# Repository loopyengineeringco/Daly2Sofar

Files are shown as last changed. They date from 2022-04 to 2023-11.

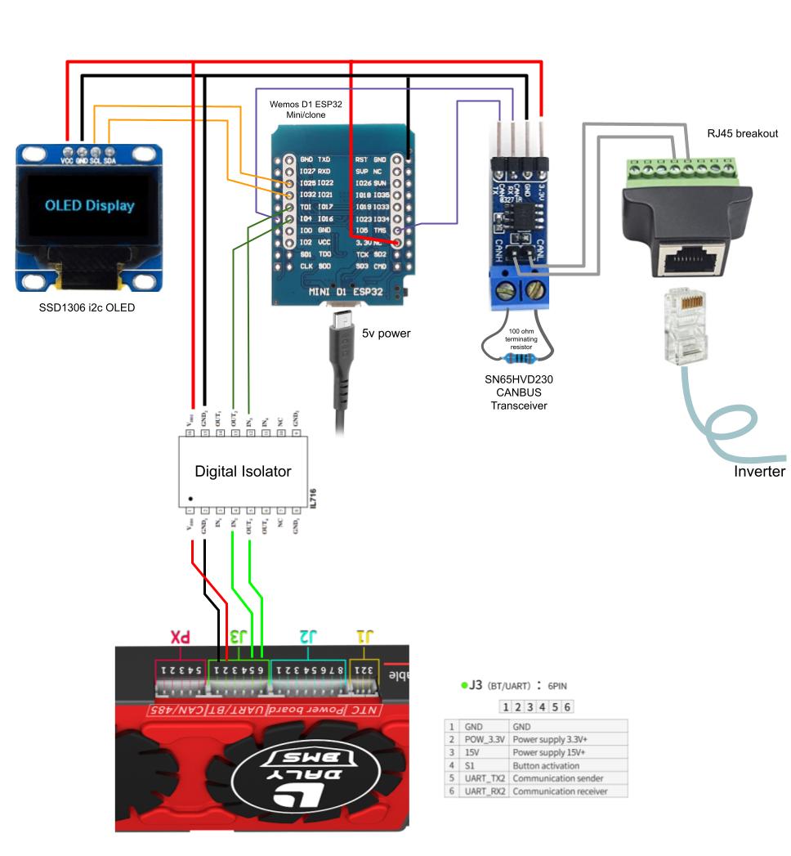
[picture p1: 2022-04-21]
Daly2Sofar schematic.jpg

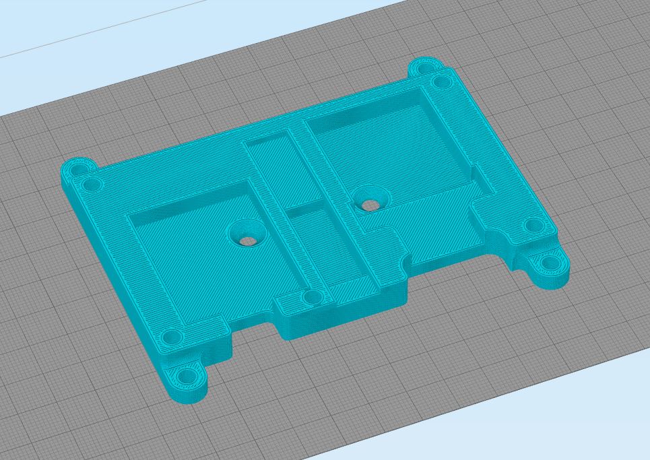
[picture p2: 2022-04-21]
3D Printables/Base_slicer.JPG

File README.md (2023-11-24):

# !!!
Due to updates to the Daly library dependency, compilation might throw an error.
Please look at the Issues page for the temporary solution while I do further testing, or use the older version of the Daly lib which is in the Arduino dependencies folder.
!!!

# Daly2Sofar v0.93 - beta
ESP32 bridge allowing Daly Smart BMS to be used with a Sofar inverter/charger (and others that use SMA CANBUS protocol).


It connects to Daly via UART and transmits to the inverter on CANBUS (SMA protocol).
At the same time, it will transmit the BMS data to an MQTT broker if it can connect to your WiFi.
If it can't connect to WiFi or your MQTT broker, it will still work as a BMS-to-Inverter bridge.
The icons on the OLED represent the WiFi & MQTT status. They will be crossed out if there is no connection.

Data comms is one way only - data is requested from Daly and sent to the Inverter & over MQTT.
May be compatible with other inverters that use the SMA protocol.

My testing showed that Daly UART port works on 3.3v. PLEASE measure yours before connecting the ESP. Some users report 5V.



Daly2Sofar_3

# PSA:
USE THIS AT YOUR OWN RISK!
Batteries are dangerous. Don't come to me if you burn your house down.
This release is a working prototype. It might freeze, there might be glitches. Your battery might overcharge/undercharge. Make sure your BMS is set up properly with your own limits.
USE THIS AT YOUR OWN RISK!

# Schematic


# Isolation
Some battery setups earth the battery negative, others don't.
For the ones that aren't earthed, you may get a ID05 Fault on the inverter when you connect canbus.
You might get a shock if you touch the comms/3v3/ground pins coming from the BMS, even though they're supposed to be only 3.3v.

Ask me how I know!

This is because the Daly UART ground is battery ground, and it makes its way to the inverter.
It might be higher or lower voltage potential, in respect to earth.

The Daly needs to be isolated in this case, using a digital isolation IC.
Opto-coupler's don't work as the signal becomes inverted. ESP32 serial can be inverted by software but Daly can't.
IL716-3E based isolator IC works, as well as the cheap off-the shelf ADUM1201 based modules.

# ESP32 pin remapping
Make sure the I2C pins are mapped correctly for the Oled to work. For me, pins 21 and 22 work great
C:\Users\XXXXX\Documents\Arduino\libraries\Adafruit_SSD1306-1.1.2\Adafruit_SSD1306.cpp
```
#define I2C_SDA 21
#define I2C_SCL 22
```

And also Serial2 needs to be correctly mapped in this file (This is Windows. Sorry I don't know where it is on a Mac)
C:\Users\XXXXX\AppData\Local\Arduino15\packages\esp32\hardware\esp32\1.0.6\cores\esp32\HardwareSerial.cpp
Look for this near the top:
```
#ifndef RX2
#define RX2 16
#endif

#ifndef TX2
#define TX2 17
#endif
```

# MQTT info:
Add your WiFi and MQTT details to the top of the sketch, as well as your battery capacity and preferred charging voltage (Capacity is broken at the moment, but the Inverter seems happy nonetheless):



Subscribe your MQTT client to:
```Daly2Sofar/state```

topics published are:
```
soc
voltage
current
power
temp
lowestcell
highestcell
cellimbalance
```

# Node-RED
For extracting the data into Home Asisstant sensors, use Node-Red. You can import the ```Daly2Sofar Node-Red to Home Assistant flow.json```flow to extract the data into sensor entities, it will look like this:
![image](https://user-images.githubusercontent.com/43951291/166910404-52b77566-ff52-444a-bd41-08b7f5ddcaa1.png)

(you may need to install Moving Average filter if you want smoothing of data)

When the battery is discharging, Node-RED will calculate the remaining battery time based on the current discharge rate.
When it's charging, it will calculate the time left to full charge.
Because charging/discharging and SOC isn't linear, this value is only a rough estimation, but useful nonetheless.

This has some hard-coded variables - it's based on a 10kWh battery and 80% DOD, and also what percentage to consider 'full' 95% in my case.
Make sure you customise them if you want to use this Flow :-)
![image](https://user-images.githubusercontent.com/43951291/166910615-47297ec8-0477-4fcf-b30d-cc008e25f745.png)

Home Assistant dashboard example
![image](https://user-images.githubusercontent.com/43951291/166928175-bbf1b5a7-a5f7-41d0-8a70-b6e47e459800.png)

# To do:
- Do proper CANBUS status check. Currently, CAN indicator will go live after the data send, whether it's succesfull or not.
- Add battery cycles: the owner of the Daly library is adding the functionality, and it will be reflected here when it's done.
- Add charge/discharge control via MQTT (as soon as it's available in the Daly lib)
- Tidy up code/refactor where poss.
- Longer term stability testing.

# Arduino dependencies

https://github.com/maland16/daly-bms-uart

https://github.com/miwagner/ESP32-Arduino-CAN

https://github.com/me-no-dev/AsyncTCP

https://github.com/marvinroger/async-mqtt-client

https://github.com/adafruit/Adafruit_SSD1306

# Notes/links

CANH & CANL can be live swapped. If display is saying all is good but inverter isn't happy, try swapping the wires.

Developed on Arduino IDE 1.8.5. Version 1.8.14 failed to compile. Downgrade if you have issues

Using arduino ESP32 Core version 1.0.6

Developed & tested with a Sofar HYD6000-ES. Should work fine with all the others, but if you test it on your inverters let me know how it goes!

Using SMA_CAN_protocol.pdf for the CAN IDs and data format info (google will find you the PDF)

Using https://cryptii.com/pipes/integer-encoder for working out hex values

VIEW TEXT > DECODE INTEGER (LITTLE ENDIAN) U16 > VIEW BYTES HEX GROUPED BY BYTES

https://www.scadacore.com/tools/programming-calculators/online-hex-converter/ for checking hex values

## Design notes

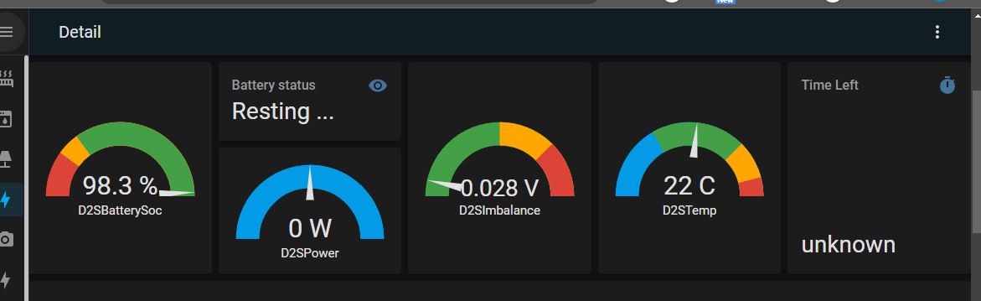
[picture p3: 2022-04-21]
Home Assistant sensors example.jpg

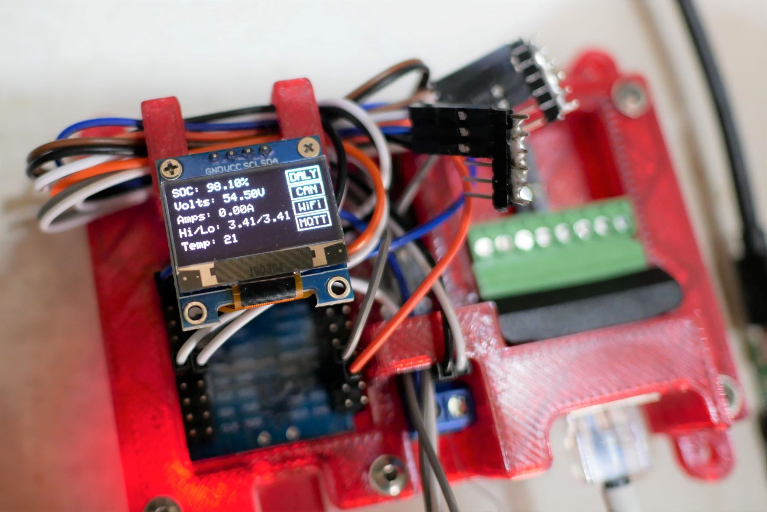
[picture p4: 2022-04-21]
Daly2Sofar_2.jpg

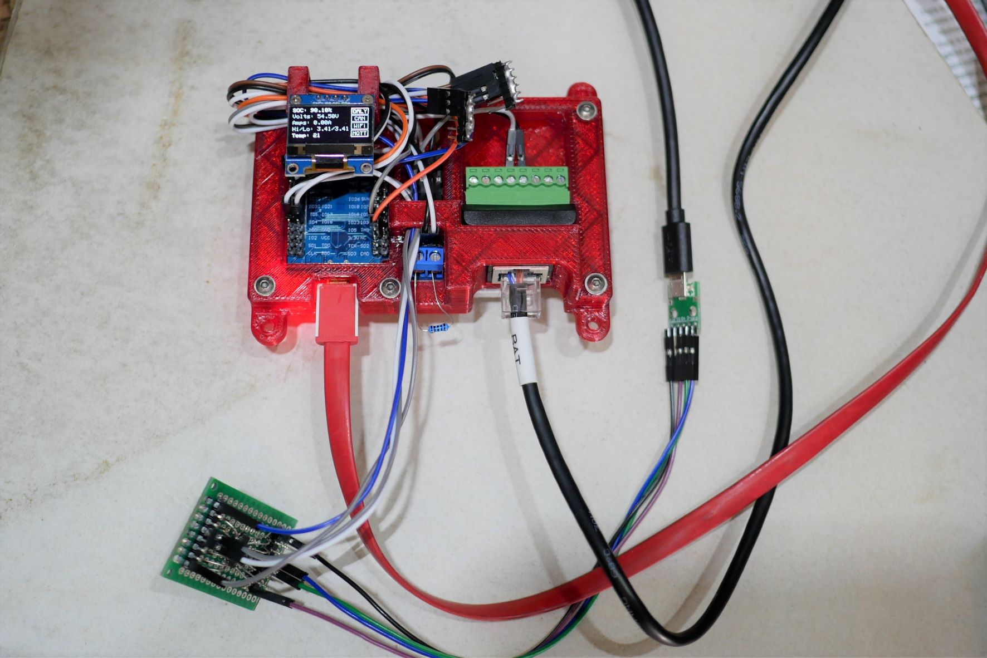
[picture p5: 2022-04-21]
Daly2Sofar_1.jpg

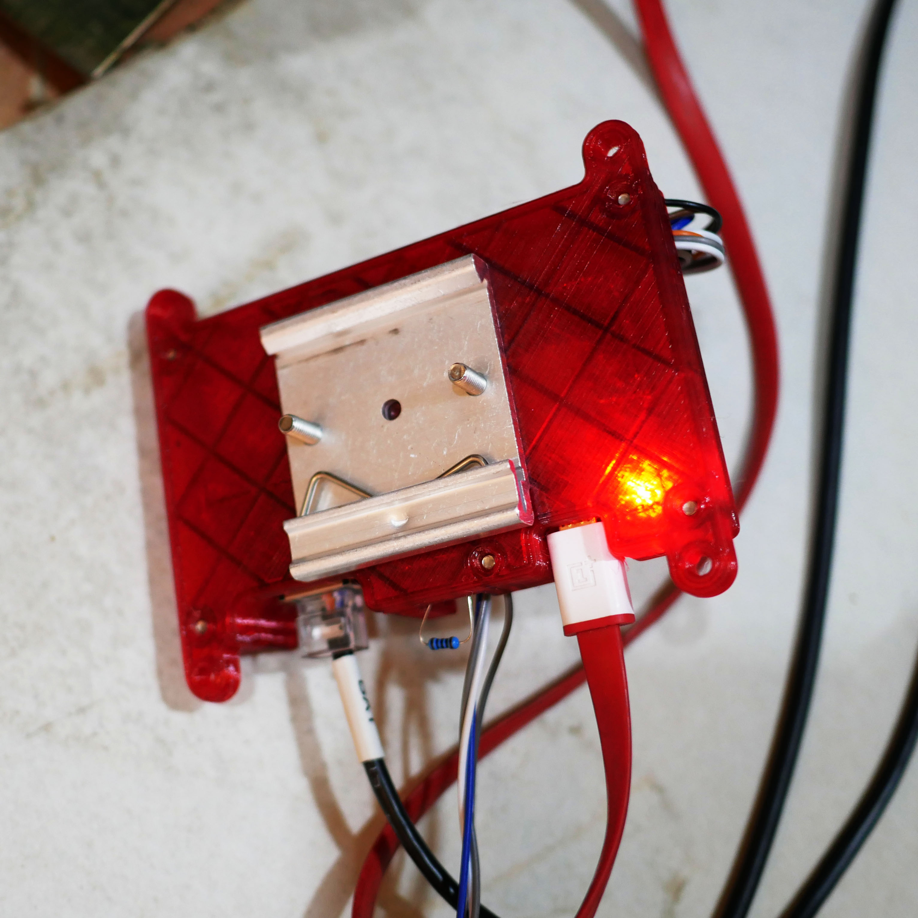
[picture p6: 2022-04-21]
Daly2Sofar_3.jpg

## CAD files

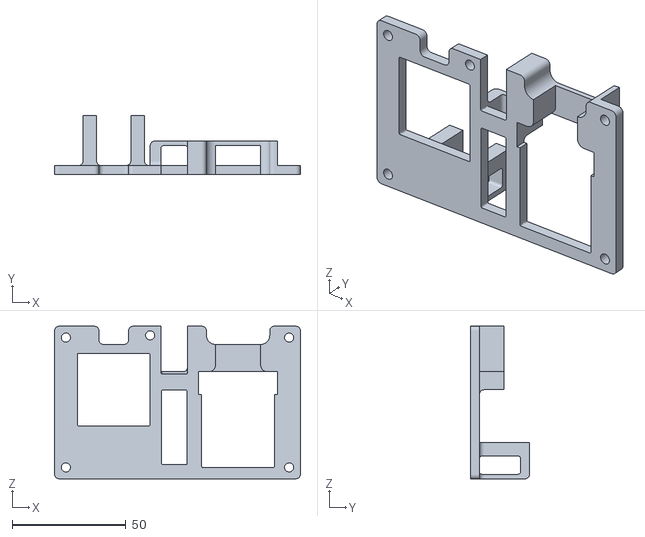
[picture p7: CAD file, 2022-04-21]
3D Printables/Daly2SofarTop_04.stl
108.0 x 26.0 x 67.0

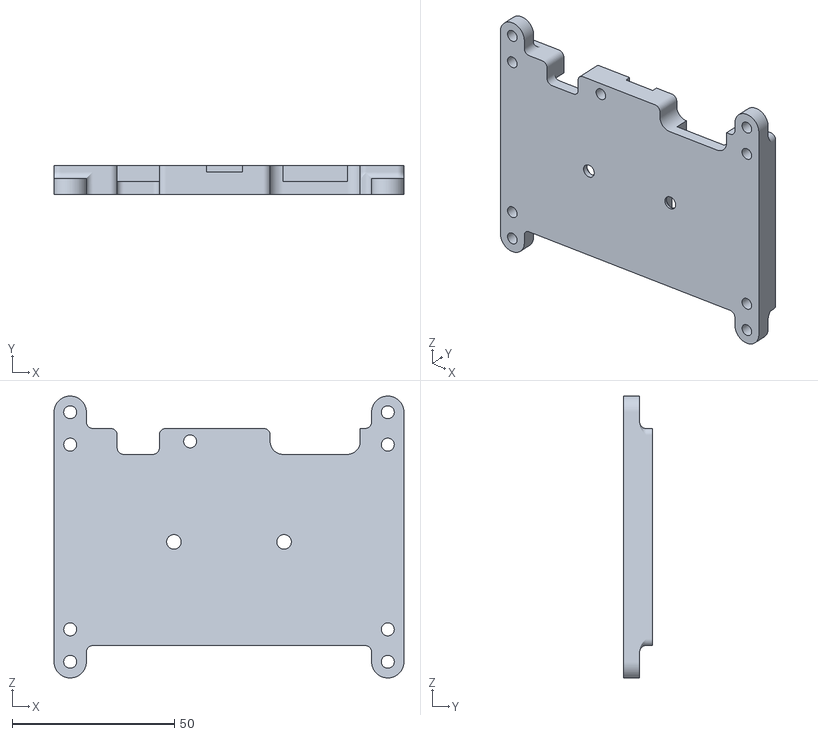
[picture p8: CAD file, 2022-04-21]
3D Printables/Daly2SofarBase_04.stl
108.0 x 9.00 x 87.0

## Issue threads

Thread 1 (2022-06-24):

Impossible to compile this code

BOBILLEChristophe, 2022-06-24:
Hello

Impossible to compile this code:

Wemos D1 ESP32
Arduino IDE

Thanks for the answer

Christophe

I_MQTTstuff:12:16: error: variable or field 'WiFiEvent' declared void
 void WiFiEvent(WiFiEvent_t event) {
                ^
I_MQTTstuff:12:16: error: 'system_event_id_t' was not declared in this scope
I_MQTTstuff:31:23: error: variable or field 'onMqttDisconnect' declared void
 void onMqttDisconnect(AsyncMqttClientDisconnectReason reason) {
                       ^
I_MQTTstuff:31:23: error: 'AsyncMqttClientDisconnectReason' was not declared in this scope
I_MQTTstuff:55:48: error: 'AsyncMqttClientMessageProperties' has not been declared
 void onMqttMessage(char* topic, char* payload, AsyncMqttClientMessageProperties properties, size_t len, size_t index, size_t total) {
                                                ^
/Users/christophe/Desktop/Daly2Sofar-main 2/Daly2Sofar_v0.92/L_GeneralFunctions.ino: In function 'void getEverythingFromDaly()':
L_GeneralFunctions:11:52: error: no matching function for call to 'Daly_BMS_UART::getPackMeasurements(float&, float&, float&)'
     bms.getPackMeasurements(volts, amps, percentage);
                                                    ^
In file included from /Users/christophe/Desktop/Daly2Sofar-main 2/Daly2Sofar_v0.92/Daly2Sofar_v0.92.ino:126:0:
/Users/christophe/Documents/Arduino/libraries/daly-bms-uart-main/daly-bms-uart.h:173:10: note: candidate: bool Daly_BMS_UART::getPackMeasurements()
     bool getPackMeasurements();
          ^
/Users/christophe/Documents/Arduino/libraries/daly-bms-uart-main/daly-bms-uart.h:173:10: note:   candidate expects 0 arguments, 3 provided
L_GeneralFunctions:28:25: error: no matching function for call to 'Daly_BMS_UART::getPackTemp(int8_t&)'
     bms.getPackTemp(temp);
                         ^
In file included from /Users/christophe/Desktop/Daly2Sofar-main 2/Daly2Sofar_v0.92/Daly2Sofar_v0.92.ino:126:0:
/Users/christophe/Documents/Arduino/libraries/daly-bms-uart-main/daly-bms-uart.h:180:10: note: candidate: bool Daly_BMS_UART::getPackTemp()
     bool getPackTemp();
          ^
/Users/christophe/Documents/Arduino/libraries/daly-bms-uart-main/daly-bms-uart.h:180:10: note:   candidate expects 0 arguments, 1 provided
L_GeneralFunctions:44:90: error: no matching function for call to 'Daly_BMS_UART::getMinMaxCellVoltage(float&, uint8_t&, float&, uint8_t&)'
     bms.getMinMaxCellVoltage(minCellVoltage, minCellNumber, maxCellVoltage, maxCellNumber);
                                                                                          ^
In file included from /Users/christophe/Desktop/Daly2Sofar-main 2/Daly2Sofar_v0.92/Daly2Sofar_v0.92.ino:126:0:
/Users/christophe/Documents/Arduino/libraries/daly-bms-uart-main/daly-bms-uart.h:187:10: note: candidate: bool Daly_BMS_UART::getMinMaxCellVoltage()
     bool getMinMaxCellVoltage();
          ^
/Users/christophe/Documents/Arduino/libraries/daly-bms-uart-main/daly-bms-uart.h:187:10: note:   candidate expects 0 arguments, 4 provided
/Users/christophe/Desktop/Daly2Sofar-main 2/Daly2Sofar_v0.92/X_Main.ino: In function 'void setup()':
X_Main:42:37: error: no matching function for call to 'AsyncMqttClient::onMessage(<unresolved overloaded function type>)'
   mqttClient.onMessage(onMqttMessage);
                                     ^
In file included from /Users/christophe/Documents/Arduino/libraries/async-mqtt-client-develop/src/AsyncMqttClient.h:4:0,
                 from /Users/christophe/Desktop/Daly2Sofar-main 2/Daly2Sofar_v0.92/Daly2Sofar_v0.92.ino:112:
/Users/christophe/Documents/Arduino/libraries/async-mqtt-client-develop/src/AsyncMqttClient.hpp:75:20: note: candidate: AsyncMqttClient& AsyncMqttClient::onMessage(AsyncMqttClientInternals::OnMessageUserCallback)
   AsyncMqttClient& onMessage(AsyncMqttClientInternals::OnMessageUserCallback callback);

ASMotionLab, 2022-06-24:
Hi @BOBILLEChristophe
I think the errors are showing that you are missing the correct libraries: do you have the Async MQTT and TCP libraries installed?

tobydavies11, 2022-06-24:
I’m also having the same issues…

the daly uart library seems to not recognise

'Daly_BMS_UART::getPackMeasurements(float&, float&, float&)'

and others

tobydavies11, 2022-06-24:
1.8.15 as per the build guide, and all the dependencies stated.

I also think the daly library has been modified.

if you remove what’s inside the brackets for get pack measurement it then compiled.

I’ve thus added;

bms.getPackMeasurements()

float volts = bms.get.packVoltage
float amps = bms.get.packCurrent
Float percentage = bms.get.packSOC

I’ve been unable to test on a live system yet to confirm if this fixes.

ASMotionLab, 2022-06-24:
Thanks guys for your work.
Looks like there's been a flurry of activity in the Daly Arduino github, so most likely the lib has changed slightly.
@tobydavies11 if you could let me know when you get a chance to test it on your live system, I'll do the updates here.
Or I might give it a test on my system tomorrow if I get some time.
Thanks!

tobydavies11, 2022-06-25:
No Probs! Thanks for great work in getting the initial up and running.

It will take me a few days to report back.

Turbojo1, 2022-09-03:
Hi, is there any update on this as I've spent all day trying to get it to work.
It's now gone past my level of expertise!

ASMotionLab, 2022-09-16:
Hi @Turbojo1

I've collected the Daly lib version that was used for the development of this into the Arduino dependencies folder.
There are other libs in there too in case it helps.
It was updated shortly after I released this, and broke the compatibility and I never quite got round to fixing this properly.
I plan to eventually, but as this is at the bottom of my priority list - try to use the older Daly lib I uploaded for now.

Willpowerandstring, 2023-05-23:
Probably a bit late for Turbojo but managed to compile on arduino 1.8.5 using the included libraries.The LCD library caused a boot loop though - I removed all references to the LCD in the code and it's working fine ( Having no LCD isn't a dealbreaker for me ). Just waiting on a CAN chip to test fully

Willpowerandstring, 2023-05-23:
>

 managed to compile on arduino 1.8.5 using the included libraries.Something in the LCD library caused a boot loop though - I removed all references to the LCD in the code and it's working fine ( Having no LCD isn't a dealbreaker for me ). Just waiting on a CAN chip to test fully.

felixganzer, 2024-02-11:
I was able to compile when I add all the source code to one .ino file.

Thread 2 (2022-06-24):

I’m also having the same issues…

BOBILLEChristophe, 2022-06-24:
I’m also having the same issues…

the daly uart library seems to not recognise

'Daly_BMS_UART::getPackMeasurements(float&, float&, float&)'

and others

_Originally posted by @tobydavies11 in https://github.com/ASMotionLab/Daly2Sofar/issues/1#issuecomment-1165622666_

BOBILLEChristophe, 2022-06-24:
Indeed you must remove the parameters of the function

```
 if (dalyRequestCounter == 1) {
    //bms.getPackMeasurements(volts, amps, percentage);
    bms.getPackMeasurements();
```

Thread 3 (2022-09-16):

Problem with compile

00gtw00, 2022-09-16:
Can someone upload project with all libraries with one is able to compile?

ASMotionLab, 2022-09-16:
Hi @00gtw00
I've collected the dependencies and uploaded them to the 'Arduino dependencies' folder.
It's most likely the Daly library that's causing compile errors - it was updated shortly after I released this, and broke the compatibility.
I plan to fix this properly eventually, but as this is at the bottom of my priority list - try to use the older Daly lib I uploaded for now.

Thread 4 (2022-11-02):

What kind of battery model emulates?

djp3k05, 2022-11-02:
Hello,
I would like to try implementing your project, but before buying the stuffs needed, I have couple of questions:
Does you project emulates any know battery model? like PYLONTECH? I own a Easun inverter (Infinisolar/Voltronic/Axperts). As my Daly bms does not have an rs485/can option (the pins are there, but it seems they are not enabled) - I found your project to be the only one to use the UART port of Daly.
As a side note, I already using a wemos d1 to read the data from BMS and send it using MQTT to HomeAssistant.

Thanks.

ASMotionLab, 2022-11-02:
Hi,
Sure - the Daly2Sofar doesn't emulate a battery system, it just speaks the default protocol that Sofar inverter understands which is the SMA protocol. It's sending all the bits of data to the right addresses that the inverter expects, and the inverter is happy, it doesn't necessarily need to know what battery system it is. But in my code I'm sending the characters S, M, A in case they make any difference, but I'm pretty sure they don't - this manufacturer name is just passed into the inverter's display and logging data. You could call it "Apple" and I don't think it would care.

I don't know if other inverters are the same.

Pylontech batteries do use a slightly different protocol - the concept is exactly the same as the SMA but the CANBUS packet addresses and structure is slightly different. I did start developing a Pylontech version too but the protocol information was half chinese, from dubious sources and hard to understand, I ran out of time and gave up, focussed on the SMA version.

The current code could be adapted quite easily to speak Pylontech, but the testing takes a long time.

So I guess the short answer is: if the inverter doesn't support SMA (Sunny Boy Storage battery) protocol then probably won't work. But if you have time/skills you could get it to work quite easily with some trial & error

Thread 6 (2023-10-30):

Not able to start CAN communicaton

197Fabian, 2023-10-30:
Hello,

I am stuck with the following problem.
The complication of the software has worked for me without problems, also the retrieval of data from the Daly BMS Works for me.
However, when running the software, the ESP always hangs at the following command:
sendCanTXFrame(XXXXX);
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

The first three commands run through but then the following function no longer works:

ESP32Can.CANWriteFrame(&tx_frame);
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

Can someone help me here?

Hardware:
-SMA Sunny Island 4.4M
-Wemons D1 ESP32 Mini/clone
-SN65HVD230 CANBUS Tranceiver
-RJ45 breakout
-SSD1306 i2c OLED
-DALY BMS

loopyengineeringco, 2023-10-30:
Hi,
Does it freeze there only while connected to canbus or also when not connected? It's good to rule out a physical canbus issue.
Is it possible that the canbus baud is mismatched? I only ever tested it with my Sofar inverter which requires 500KBPS.

197Fabian, 2023-10-30:
Hi,

the error always happens no matter if the inverter is connected or not.
Furthermore, the display never shows a CAN connection.

Sunny Island 4.4m requires the following:
Values to Sunny Island must not be sent out faster than every 200msec (inhibit time).
CAN data is transmitted with encoding in little endian - low byte first – unless stated otherwise

other information I don´t find.

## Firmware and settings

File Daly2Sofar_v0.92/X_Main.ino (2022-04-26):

void setup() {
  //rtc_wdt_protect_off();
  //rtc_wdt_disable();

  Serial.begin(115200);
  Serial.println("Daly2Sofar-UARTtoCANBUS v1");
  
  // Set CAN pins and baudrate
  CAN_cfg.speed=CAN_SPEED_500KBPS;
  CAN_cfg.tx_pin_id = GPIO_NUM_5;
  CAN_cfg.rx_pin_id = GPIO_NUM_4;
  
  // Create a queue for CAN receiving */
  CAN_cfg.rx_queue = xQueueCreate(rx_queue_size,sizeof(CAN_frame_t));
  
  // Initialize CAN Module
  ESP32Can.CANInit();
  
  // Initialise the Daly comms
  bms.Init();

  Wire.begin();   // sda= GPIO_21 /scl= GPIO_22
  display.begin(SSD1306_SWITCHCAPVCC, 0x3C);  // initialize OLED with the I2C addr 0x3C (for the 64x48)
  display.clearDisplay();
  display.display();
  oledMessage("Hi", "Ola!", "Hello", "Labas", "Zdravstvuyte");
  //delay(500);

  mqttReconnectTimer = xTimerCreate("mqttTimer", pdMS_TO_TICKS(5000), pdFALSE, (void*)0, reinterpret_cast<TimerCallbackFunction_t>(connectToMqtt));
  wifiReconnectTimer = xTimerCreate("wifiTimer", pdMS_TO_TICKS(2000), pdFALSE, (void*)0, reinterpret_cast<TimerCallbackFunction_t>(connectToWifi));
  mqttPublishXTimer = xTimerCreate("mqttPubTimer", pdMS_TO_TICKS(2000), pdFALSE, (void*)0, reinterpret_cast<TimerCallbackFunction_t>(sendMQTTData));
  dalyRetryXTimer = xTimerCreate("dalyRetryTimer", pdMS_TO_TICKS(200), pdFALSE, (void*)0, reinterpret_cast<TimerCallbackFunction_t>(dalyRetry));


  WiFi.onEvent(WiFiEvent);

  mqttClient.setCredentials(mqttUser, mqttPassword);
  mqttClient.onConnect(onMqttConnect);
  mqttClient.onDisconnect(onMqttDisconnect);
  mqttClient.onSubscribe(onMqttSubscribe);
  mqttClient.onUnsubscribe(onMqttUnsubscribe);
  mqttClient.onMessage(onMqttMessage);
  mqttClient.onPublish(onMqttPublish);
  mqttClient.setServer(MQTT_HOST, MQTT_PORT);

  connectToWifi();
}


void loop() {
  unsigned long currentMillisUARTCAN = millis();
  if (currentMillisUARTCAN - previousMillisUARTCAN >= intervalUARTCAN) {
    previousMillisUARTCAN = currentMillisUARTCAN;
    
    getEverythingFromDaly();
  
    if (BMSOnline) {
      updateTXFrames();
  
      sendCanTXFrame(CANData351, 8); // 0x0351 - 8 bytes
      sendCanTXFrame(CANData355, 6); // 0x0355 - 6 bytes
      sendCanTXFrame(CANData356, 6); // 0x0356 - 6 bytes
      sendCanTXFrame(CANData35A, 8); // 0x035A - 8 bytes
      sendCanTXFrame(CANData35B, 2); // 0x035B - 2 bytes
      sendCanTXFrame(CANData35E, 8); // 0x035E - 8 bytes
      sendCanTXFrame(CANData35F, 8); // 0x035F - 8 bytes
    }
  }
}

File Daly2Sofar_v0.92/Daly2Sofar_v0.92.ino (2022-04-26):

/*
Daly2Sofar

An ESP32 based bridge that allows Daly Smart BMS to be used with a Sofar inverter/charger (and others that use SMA protocol).
It connects to Daly via UART and transmits to the inverter on CANBUS (SMA protocol).
At the same time, it will transmit the BMS data to an MQTT broker if it can connect to your WiFi.
If it can't connect to WiFi or your MQTT broker, it will still work as a BMS-to-Inverter bridge.

Data comms is one way only - data is requested from Daly and sent to the Inverter & over MQTT.
May be compatible with other inverters that use the SMA protocol.

My testing showed that Daly UART port works on 3.3v. PLEASE measure yours before connecting the ESP. Some users report 5V.


****** a point on isolation *
Some battery setups earth the battery negative, others don't.
For the ones that aren't earthed, you may get a ID05 Fault on the inverter when you connect canbus.
This is because the Daly UART ground is battery ground, and it makes its way to the inverter.
The Daly needs to be isolated in this case, using a digital isolation IC.
Opto-coupler's don't work as the signal becomes inverted. ESP32 serial can be inverted by software but Daly can't.
I used a IL716-3E isolator IC and soldered dupont pins to it's legs - it's tiny, it's not easy!
If you find an isolator IC module that is cheap and works without soldering, please let me know!
******


Using SMA_CAN_protocol.pdf for the CAN IDs and data format info (google will find you the PDF)

Using https://cryptii.com/pipes/integer-encoder for working out hex values
VIEW TEXT > DECODE INTEGER (LITTLE ENDIAN) U16 > VIEW BYTES HEX GROUPED BY BYTES

https://www.scadacore.com/tools/programming-calculators/online-hex-converter/ for checking hex values
icons made with https://www.pixilart.com/draw/icon-maker-82d9ebbc1fc1fec#
converted with https://diyusthad.com/image2cpp



****** a point on ESP32 pin remapping *
Make sure the I2C pins are mapped correctly for the Oled to work. For me, pins 21 and 22 work great
C:\Users\XXXXX\Documents\Arduino\libraries\Adafruit_SSD1306-1.1.2\Adafruit_SSD1306.cpp
#define I2C_SDA 21
#define I2C_SCL 22

And also Serial2 needs to be correctly mapped in this file (This is Windows. Sorry I don't know where it is on a Mac)
C:\Users\XXXXX\AppData\Local\Arduino15\packages\esp32\hardware\esp32\1.0.6\cores\esp32\HardwareSerial.cpp
Look for this near the top:
#ifndef RX2
#define RX2 16
#endif

#ifndef TX2
#define TX2 17
#endif
******


MQTT info:
Subscribe your MQTT client to:
Daly2Sofar/state

topics published are:
soc
voltage
current
power
temp
lowestcell
highestcell
cellimbalance

For extracting the data into Home Asisstant sensors, use Node-Red. Have a look at the github for an example Node-Red setup.

To do:
- Do proper CANBUS status check. Currently, CAN indicator will go live after the data send, whether it's succesfull or not. CAN only goes off if BMS not found.
- Need to figure out how to obtain battery cycles from BMS.
- Tidy up code/refactor where poss.
- Longer term stablity testing.

Notes/dependencies:
- Developed on Arduino IDE 1.8.5. IDE version 1.6.14 failed to compile. Downgrade if you have issues
- Using arduino ESP32 Core version 1.0.6
- https://github.com/maland16/daly-bms-uart
- https://github.com/miwagner/ESP32-Arduino-CAN
- https://github.com/me-no-dev/AsyncTCP
- https://github.com/marvinroger/async-mqtt-client

*/

// BATTERY CAPACITY (Doesn't really matter, as it's the BMS that works out the SOC)
uint16_t batteryCapacity = 190; // Battery capacity - in AH.
float batteryChargeVoltage = 55; // Set your charge voltage - this doesn't come from BMS.

// ENTER YOUR WIFI & MQTT BROKER DETAILS HERE

#define WIFI_SSID "yourwifiname"
#define WIFI_PASSWORD "yourwifipassword"
static const char mqttUser[] = "yourmqttlogin";
static const char mqttPassword[] = "yourmqttpassword";
const char* deviceName = "Daly2Sofar"; //Device name is used as the MQTT base topic.

#define MQTT_HOST IPAddress(192, 168, 0, 206) //replace with your MQTT server IP
#define MQTT_PORT 1883





#include <WiFi.h>
extern "C" {
  #include "freertos/FreeRTOS.h"
  #include "freertos/timers.h"
}
#include <AsyncMqttClient.h>

AsyncMqttClient mqttClient;


// ESP32 CAN Library: https://github.com/miwagner/ESP32-Arduino-CAN
#include <ESP32CAN.h>
#include <CAN_config.h>
CAN_device_t CAN_cfg;
CAN_frame_t tx_frame;
const int rx_queue_size = 10;       // Receive Queue size
///////////////////////////////////////////////////////////////////

// Daly UART library: https://github.com/maland16/daly-bms-uart
#include <daly-bms-uart.h>
Daly_BMS_UART bms(Serial2);
// Vars for BMS data
boolean BMSOnline = false;
boolean CANOnline = false;
float volts = 0;
float amps = 0;
float percentage = 0;
int8_t temp = 0;

float maxCellVoltage = 0;
float minCellVoltage = 0;
uint8_t maxCellNumber = 0;
uint8_t minCellNumber = 0;
int16_t watts = 0;
uint16_t cellImbalance = 0; // in millivolts
///////////////////////////////////////////////////////////////////

// OLED stuff
#include <Wire.h>
#include <Adafruit_GFX.h>
#include <Adafruit_SSD1306.h>
#define OLED_RESET 0  // GPIO0
Adafruit_SSD1306 display(OLED_RESET);
String oledLine1;
String oledLine2;
String oledLine3;
String oledLine4;
String oledLine5;
////////////////////////////////////////////////////////






TimerHandle_t mqttReconnectTimer;
TimerHandle_t wifiReconnectTimer;
TimerHandle_t mqttPublishXTimer;
TimerHandle_t dalyRetryXTimer;


bool WiFiStatus = false;
bool MQTTStatus = false;

uint8_t dalyRequestCounter = 0;

// USER SETUP VALUES:
unsigned long previousMillisUARTCAN = 0;   // will store last time a CAN Message was send
const int intervalUARTCAN = 1000;          // interval at which send CAN Messages (milliseconds)

unsigned long previousMillisWIFIMQTT = 0;
const int intervalWIFIMQTT = 2000; 


/*
// PYLON GENERAL LITHIUM EMULATION
// Constructing a test data packet. Little endian, 8 byte messages, 4 halfwords. CAN ID (11bit id 0x351 split into 2 bytes, little endian) for the CAN send function, to reduce manual labour.
byte CANData1[]=   {0x03, 0x51,  // CAN ID (11bit id 0x351 split into 2 bytes, little endian). Battery charge voltage, DC charge current limitation, DC discharge currentlimitation, discharge voltage
                    0x14, 0x02,   // Battery charge voltage - U16 - 0.1 scale. 41-63. Default 60 (560)
                    0x74, 0x0E,   // DC charge current limitation - S16 - 0.1 scale. 0-1200. Default 99.9 (999)
                    0x74, 0x0E,   // DC discharge current limitation - S16 - 0.1 scale. 0-1200. Test: 99.9 (999)
                    0xCC, 0x01};  // Voltage discharge limit - U16 - 0.1 scale. 41-48. Default 41.5 (415)
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

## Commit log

2022-04-21 Initial upload
    [Daly2SofarBase_04.stl, Daly2SofarTop_04.stl]
2022-04-21 Create Daly2Sofar schematic.jpg
2022-04-21 Create Daly2Sofar Node-Red to Home Assistant flow.json
2022-04-21 Create Home Assistant sensors example.jpg
2022-04-21 Added 100r resistor description
2022-04-22 MQTT code changes
    Fixed esp32 crash after reconnecting to MQTT.
    [I_MQTTstuff.ino, J_CANBUSstuff.ino, K_OledStuff.ino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]
2022-04-26 Update
    ESP32 crash fix (boot loop)
    Inverter now sees battery capacity from top of the sketch
    [Daly2Sofar_v0.92.ino, I_MQTTstuff.ino, J_CANBUSstuff.ino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]
2022-05-05 Node-Red flow update
    "Time left" sensor now shows the time left to full charge as well as time left when discharging.
    Small other fixes.
2022-05-05 Update Daly2Sofar Node-Red to Home Assistant flow.json
2022-05-05 Node red flow updates
2023-11-24 Update README.md
    Added info about ADUM1201 magnetic isolator - tested as working
